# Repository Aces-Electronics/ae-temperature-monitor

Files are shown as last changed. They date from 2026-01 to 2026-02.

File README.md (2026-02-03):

# AE Temperature Monitor Firmware
Firmware for the Aces Electronics Temperature Monitor, utilizing ESP-NOW for low-latency communication with the Smart Shunt gateway.

## Features
- **Remote Monitoring**: Measures temperature using a high-accuracy sensor.
- **Battery Powered**: Optimized for low-power operation.
- **Wireless Relay**: Transmits data to the Smart Shunt via ESP-NOW.
- **Auto-Discovery**: Automatically detected and registered by the Smart Shunt and Cloud Dashboard.

## Communication Protocol (ESP-NOW)
The Sensor broadcasts a `struct_message_temp_sensor` payload which is received by the Smart Shunt. The Shunt then relays this data to the Cloud Dashboard for real-time alerts and historical logging.

## Build & Flash
The project uses PlatformIO.
```bash
pio run -t upload
pio run -t upload
```

## OTA Reliability
- **Loop Prevention**: Rejects updates if the version matches the currently installed firmware.
- **JIT Delivery**: Updates are pushed via the Shunt gateway immediately after an uplink.

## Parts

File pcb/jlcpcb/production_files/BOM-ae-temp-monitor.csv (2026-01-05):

Comment | Designator | Footprint | LCSC | Quantity
SW_Push | SW1,SW2 | ALPSALPINE-SKSCLBE010_C115361 | C115361 | 2
100nF | C1,C2,C3,C4,C5 | C_0402_1005Metric | C1525 | 5
1N5819WS | D1 | D_SOD-323 | C191023 | 1
10uF | C6,C7 | C_0603_1608Metric | C19702 | 2
100k | R2 | R_0402_1005Metric | C25741 | 1
5.1k | R1,R3,R4,R5,R6 | R_0402_1005Metric | C25905 | 5
ESP32-C3-MINI-1 | U1 | ESP32-C3-MINI-1 | C2838502 | 1
AP2112K-3.3 | U4 | SOT-23-5 | C51118 | 1
USB_C_Receptacle_USB2.0 | J1 | USB_C_Receptacle_GCT_USB4110 | C5187472 | 1
AP3415E | Q1 | SOT-23 | C5189719 | 1
Battery | BT2 | BatteryHolder_BH-AAA-B5AK001_C964882 | C964882 | 1
WS2812-2020 | D2 | LED_WS2812B-2020_PLCC4_2.0x2.0mm | C965555 | 1
TMP102xxDRL | U2 | SOT-563 | C99269 | 1

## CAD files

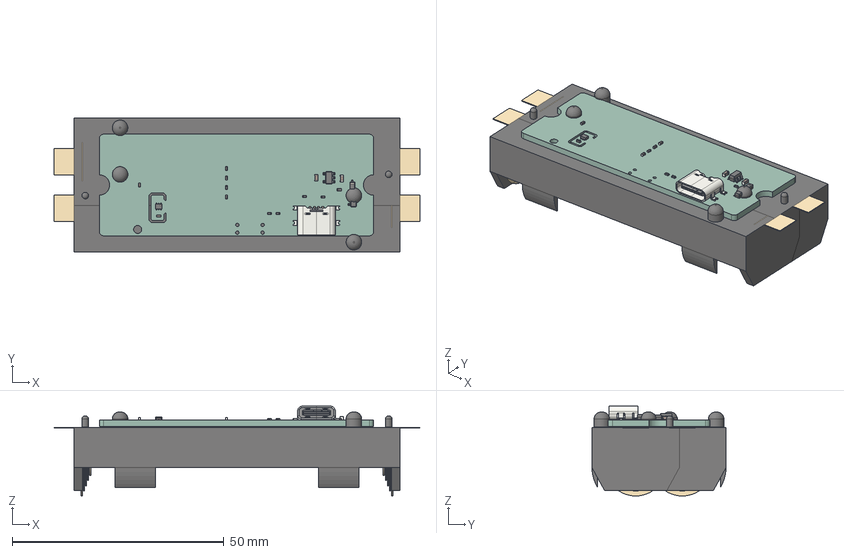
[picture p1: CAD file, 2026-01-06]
pcb/ae-temp-monitor.step
86.4 x 31.7 x 21.2 mm
C_0402_1005Metric x 5
USB_C_Receptacle_GCT_USB4135-GF-A_6P_TopMnt_Horizontal
R_0402_1005Metric x 6
SOT-563
SOT-23
D_SOD-323
C_0603_1608Metric x 2
SOT-23-5
BatteryHolder_Keystone_1042_1x18650 x 2
ae-temp-monitor_PCB

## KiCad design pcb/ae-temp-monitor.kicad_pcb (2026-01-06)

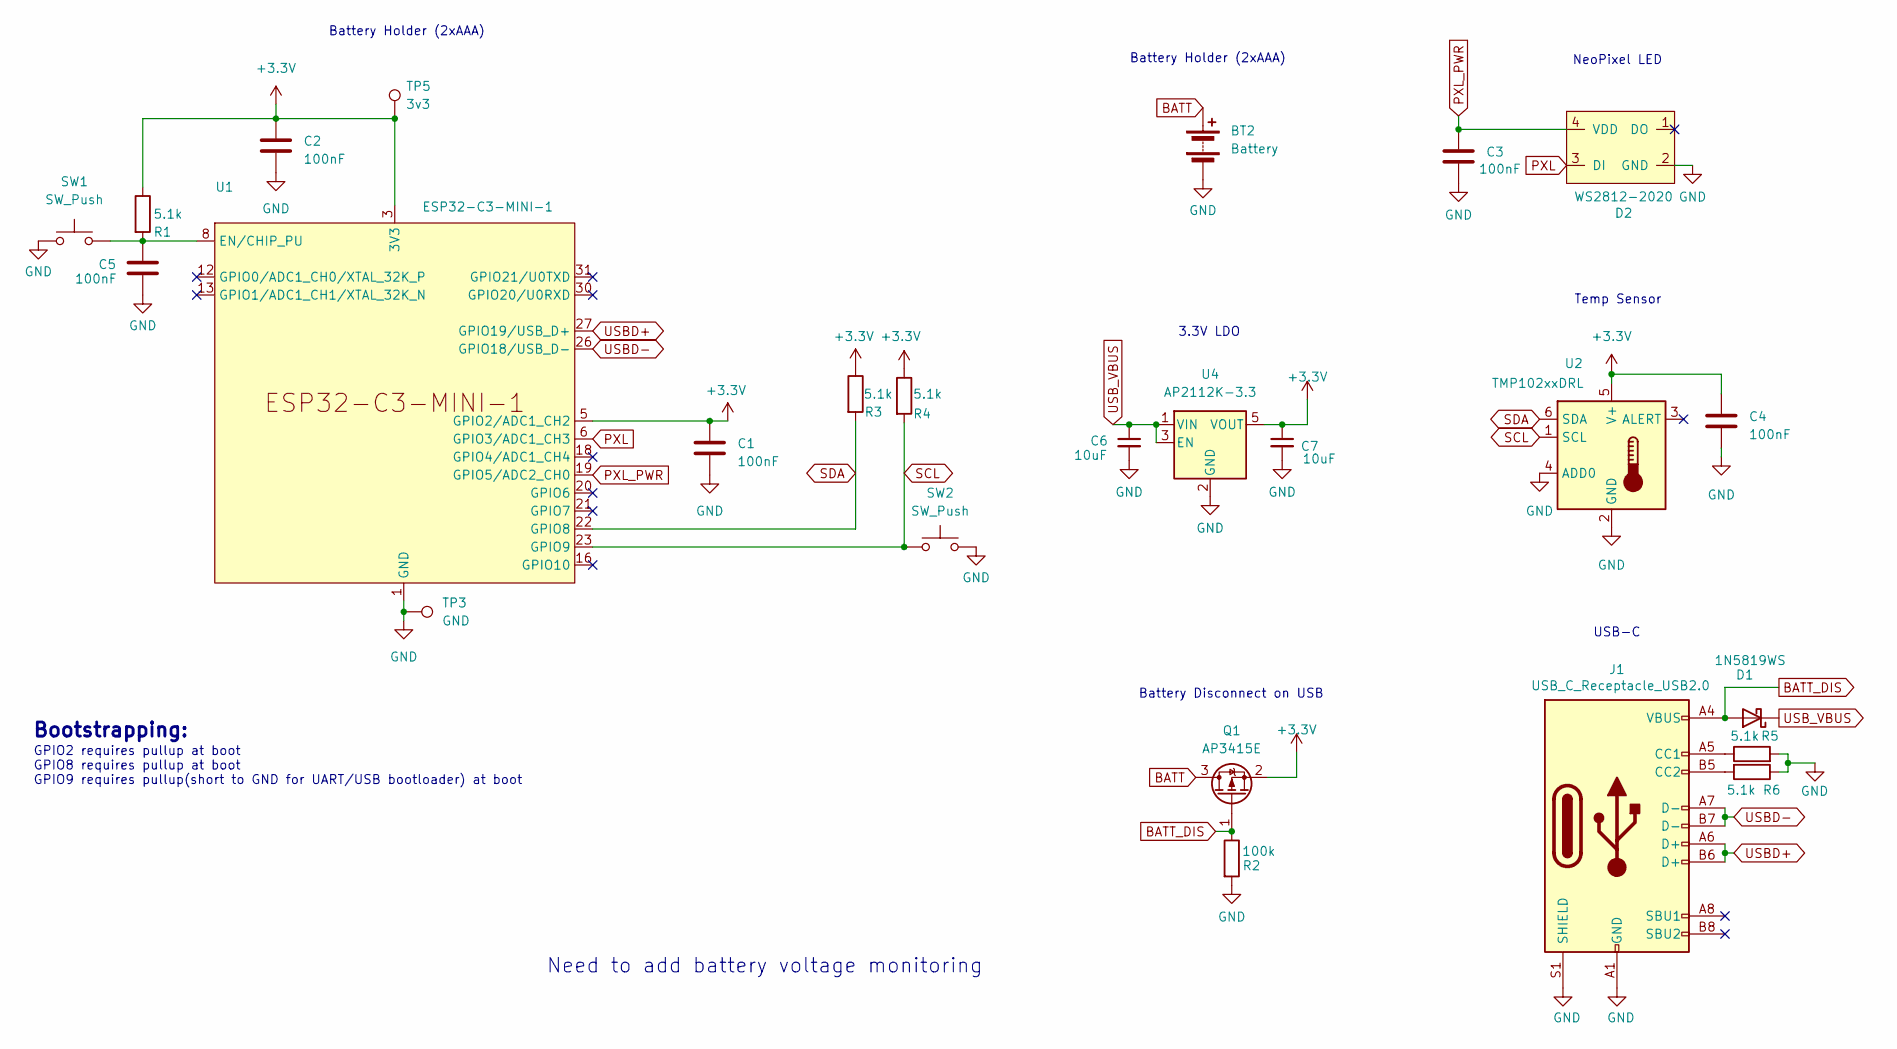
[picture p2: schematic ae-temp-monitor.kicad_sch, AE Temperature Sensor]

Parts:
BT2: Battery; BatteryHolder_BH-AAA-B5AK001_C964882; lcsc C964882
C1, C2, C3, C4, C5: 100nF; C_0402_1005Metric; lcsc C1525
C6, C7: 10uF; C_0603_1608Metric; lcsc C19702
D1: 1N5819WS; D_SOD-323; lcsc C191023
D2: WS2812-2020; LED_WS2812B-2020_PLCC4_2.0x2.0mm; lcsc C965555
J1: USB_C_Receptacle_USB2.0; USB_C_Receptacle_GCT_USB4110; lcsc C5187472
Q1: AP3415E; SOT-23; lcsc C2876004
R1, R3, R4, R5, R6: 5.1k; R_0402_1005Metric; lcsc C25905
R2: 100k; R_0402_1005Metric; lcsc C25741
SW1, SW2: SW_Push; ALPSALPINE-SKSCLBE010_C115361; lcsc C115361
TP3: GND; TestPoint_Pad_D1.0mm
TP5: 3v3; TestPoint_Pad_D1.0mm
U1: ESP32-C3-MINI-1; lcsc C5290152
U2: TMP102xxDRL; SOT-563; lcsc C99269
U4: AP2112K-3.3; SOT-23-5; lcsc C51118

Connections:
+3.3V: C1.1, C2.1, C4.1, C7.1, Q1.2 (S), R1.1, R3.1, R4.1, TP5.1, U1.3 (3V3), U1.5 (GPIO2/ADC1_CH2), U2.5 (V+), U4.5 (VOUT)
BATT: BT2.1 (+), Q1.3 (D)
BATT_DIS: D1.2 (A), J1.A4 (VBUS), J1.A9 (VBUS), J1.B4 (VBUS), J1.B9 (VBUS), Q1.1 (G), R2.1
GND: BT2.2 (-), C1.2, C2.2, C3.2, C4.2, C5.2, C6.2, C7.2, D2.2 (GND), J1.A1 (GND), J1.A12 (GND), J1.B1 (GND), J1.B12 (GND), J1.S1 (SHIELD), R2.2, R5.2, R6.1, SW1.2, SW2.2, TP3.1, U1.1 (GND), U1.2 (GND), U1.11 (GND), U1.14 (GND), U1.36 (GND), U1.37 (GND), U1.38 (GND), U1.39 (GND), U1.40 (GND), U1.41 (GND), U1.42 (GND), U1.43 (GND), U1.44 (GND), U1.45 (GND), U1.46 (GND), U1.47 (GND), U1.48 (GND), U1.49 (GND), U1.50 (GND), U1.51 (GND), U1.52 (GND), U1.53 (GND), U2.2 (GND), U2.4 (ADD0), U4.2 (GND)
unnamed: J1.A5 (CC1), R5.1
unnamed: J1.B5 (CC2), R6.2
unnamed: C5.1, R1.2, SW1.1, U1.8 (EN/CHIP_PU)
PXL: D2.3 (DI), U1.6 (GPIO3/ADC1_CH3)
PXL_PWR: C3.1, D2.4 (VDD), U1.19 (GPIO5/ADC2_CH0)
SCL: R4.2, SW2.1, U1.23 (GPIO9), U2.1 (SCL)
SDA: R3.2, U1.22 (GPIO8), U2.6 (SDA)
USBD+: J1.A6 (D+), J1.B6 (D+), U1.27 (GPIO19/USB_D+)
USBD-: J1.A7 (D-), J1.B7 (D-), U1.26 (GPIO18/USB_D-)
USB_VBUS: C6.1, D1.1 (K), U4.1 (VIN), U4.3 (EN)

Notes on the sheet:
Bootstrapping:
Battery Disconnect on USB
Temp Sensor
3.3V LDO
GPIO2 requires pullup at boot GPIO8 requires pullup at boot GPIO9 requires pullup(short to GND for UART/USB bootloader) at boot
NeoPixel LED
Need to add battery voltage monitoring
USB-C
Battery Holder (2xAAA)

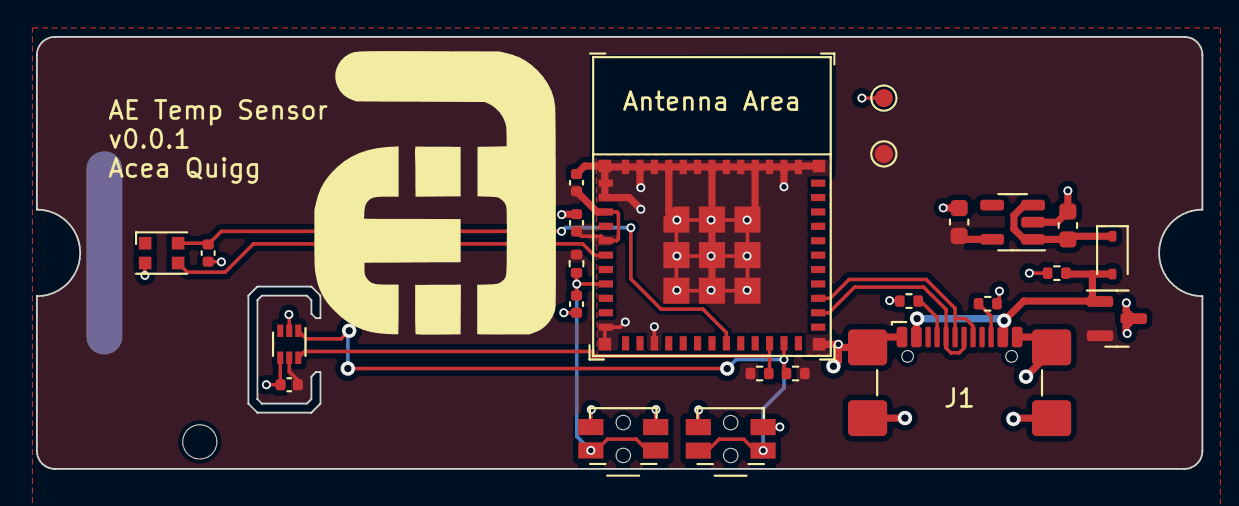
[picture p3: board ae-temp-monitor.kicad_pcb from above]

Board: 2 copper layers, 64.8 x 24.0 mm, 25 parts (1 on the bottom side), 14 nets.

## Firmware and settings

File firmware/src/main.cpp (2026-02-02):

#include <Arduino.h>
#include <Wire.h>
#include <Preferences.h>
#include "drivers/tmp102.h"
#include "drivers/neopixel.h"
#include "services/ble_service.h"
#include <services/espnow_service.h>
#include <nvs_flash.h>
#include <driver/gpio.h>
#include <WiFiClientSecure.h>

// Pins
#define I2C_SDA 8
#define I2C_SCL 9
#define NEOPIXEL_PWR 5
#define NEOPIXEL_PWR 5
#define NEOPIXEL_DATA 3
#define BOOT_PIN 9

#include <OTA-Hub.hpp>
#include <ota-github-cacerts.h>

// Globals
TMP102 tmp102;
StatusLed statusLed(NEOPIXEL_PWR, NEOPIXEL_DATA);
Preferences preferences;

// Constants
#define DEFAULT_SLEEP_MS 900000 // 15 minutes
#define AWAKE_TIME_MS 30000     // Stay awake for 30s to allow connections

unsigned long stateStartTime = 0;
bool isStayingAwake = false;

uint8_t g_pairedMac[6] = {0}; // Global storage for paired MAC
bool g_isTimerWakeup = false;

volatile bool g_indirectOtaPending = false;
struct_message_ota_trigger g_otaTrigger;

void onDataRecv(const uint8_t * mac, const uint8_t *incomingData, int len) {
    if (len == sizeof(struct_message_ota_trigger)) {
        struct_message_ota_trigger trigger;
        memcpy(&trigger, incomingData, sizeof(trigger));
        if (trigger.messageID == 110) {
            trigger.version[sizeof(trigger.version)-1] = '\0'; // Safety
            Serial.printf("[ESP-NOW] OTA Trigger: Ver='%s' (Current='%s'), Force=%d\n", 
                          trigger.version, OTA_VERSION, trigger.force);

            if (!trigger.force && strcmp(trigger.version, OTA_VERSION) == 0) {
                Serial.println("[ESP-NOW] OTA Ignored: Already on target version.");
                return;
            }

            Serial.println("[ESP-NOW] OTA Trigger Accepted!");
            memcpy((void*)&g_otaTrigger, &trigger, sizeof(g_otaTrigger));
            g_indirectOtaPending = true;
        }
    }
}

void setup() {
    Serial.begin(115200);
    // Wait a bit for serial if USB connected
    delay(1000); 
    Serial.println("AE Temp Sensor Starting...");
    
    gpio_hold_dis((gpio_num_t)NEOPIXEL_PWR);
    gpio_hold_dis((gpio_num_t)NEOPIXEL_DATA); // Release Data Pin Hold
    gpio_deep_sleep_hold_dis(); 
    gpio_deep_sleep_hold_dis(); // Ensure global hold is off if used
    
    // Init Boot Pin
    pinMode(BOOT_PIN, INPUT_PULLUP);

    // Check Wakeup Cause
    if (esp_sleep_get_wakeup_cause() == ESP_SLEEP_WAKEUP_TIMER) {
        g_isTimerWakeup = true;
        Serial.println("Wakeup: TIMER (Fast Sleep Mode)");
    } else {
        Serial.println("Wakeup: MANUAL/POWER (POR) -> Staying Awake 30s");
        isStayingAwake = true; // Ensure 30s awake window on boot/manual reset
    }

    // Init NVS
    preferences.begin("ae-temp", false);
    uint32_t sleepInterval = preferences.getUInt("sleep_ms", DEFAULT_SLEEP_MS);
    
    // Load Name Suffix (previously "name")
    String nameSuffix = preferences.getString("name", ""); 
    Serial.printf("DEBUG: Loaded Name Suffix from NVS: '%s'\n", nameSuffix.c_str());
    
    String deviceName = "AE Temp Sensor";
    if (nameSuffix.length() > 0) {
        deviceName += " - " + nameSuffix;
    }
    Serial.printf("DEBUG: Full Device Name for BLE: '%s'\n", deviceName.c_str());
    
    bleService.setSleepInterval(sleepInterval);
    bleService.setNameCallback([](const char* suffix) {
        // Save only the suffix
        preferences.putString("name", suffix);
        Serial.printf("Saved new name suffix to NVS: %s\n", suffix);
    });

    bool isPaired = preferences.getBool("paired", false);
    bleService.setPaired(isPaired);
    bleService.setPairedCallback([](bool paired) {
        preferences.putBool("paired", paired);
        Serial.printf("Saved Paired Status to NVS: %s\n", paired ? "True" : "False");
        statusLed.flash(0, 128, 0, 500); // Green confirmation (Dimmed)
        
        if (!paired) {
            Serial.println("Factory Reset/Unpair Triggered!");
            // Visual confirmation: Long Red Flash
            statusLed.flash(255, 0, 0, 1000); 
            
            // Wipe Everything
            preferences.clear(); // Explicitly clear the 'ae-temp' namespace keys
            nvs_flash_erase();   // Wipe the underlying partition
            nvs_flash_init();
            
            Serial.println("NVS Erased. Restarting...");
            delay(500);
            ESP.restart();
        }
    });
    
    // Handle JSON Pairing Data {"gauge_mac":"...", "key":"..."}
    bleService.setPairingDataCallback([](const char* json) {
        Serial.printf("Processing Pairing JSON/CMD: %s\n", json);
        
        if (String(json) == "PAIRING") {
            Serial.println("Received PAIRING command via BLE. Forcing broadcast mode for 5 mins.");
            espNowService.setForceBroadcast(true);
            // We use a global or local static to track time
            return;
        }

        // Minimal JSON parsing to avoid heavy library usage if possible, or use ArduinoJson if available (user has it in other projects)
        // Let's assume ArduinoJson is available or use String search
        String j = String(json);
        
        // Extract MAC
        int macIdx = j.indexOf("gauge_mac");
        String gaugeMacStr = "";
        if (macIdx > 0) {
            int start = j.indexOf(":", macIdx) + 1;
            // Skip quotes
            while (j[start] == ' ' || j[start] == '"') start++;
            int end = j.indexOf('"', start);
            gaugeMacStr = j.substring(start, end);
        }
        
        // Extract Key
        int keyIdx = j.indexOf("key");
        String keyStr = "";
        if (keyIdx > 0) {
            int start = j.indexOf(":", keyIdx) + 1;
            while (j[start] == ' ' || j[start] == '"') start++;
            int end = j.indexOf('"', start);
            keyStr = j.substring(start, end);
        }
        
        Serial.printf("Extracted MAC: %s, Key: %s\n", gaugeMacStr.c_str(), keyStr.c_str());
        
        if (gaugeMacStr.length() > 0 && keyStr.length() == 32) {
             preferences.putString("p_mac", gaugeMacStr);
             preferences.putString("p_key", keyStr);
             
             // Update Global MAC for main loop
             sscanf(gaugeMacStr.c_str(), "%hhx:%hhx:%hhx:%hhx:%hhx:%hhx", 
               &g_pairedMac[0], &g_pairedMac[1], &g_pairedMac[2], 
               &g_pairedMac[3], &g_pairedMac[4], &g_pairedMac[5]);
             
             // Update runtime peer immediately
             espNowService.addSecurePeer(gaugeMacStr.c_str(), keyStr.c_str());
             
             bleService.updatePaired(true); // Notify App success
        } else {
            Serial.println("Invalid Pairing Data");
        }
    });

    bleService.setWifiCallback([](const char* ssid, const char* pass) {
        Serial.printf("Received WiFi Creds via BLE: SSID='%s'\n", ssid);
        // Store in global trigger struct for upcoming OTA
        memset(&g_otaTrigger, 0, sizeof(g_otaTrigger)); // Clear first to avoid garbage
        g_otaTrigger.messageID = 110;
        strncpy(g_otaTrigger.ssid, ssid, sizeof(g_otaTrigger.ssid) - 1);
        strncpy(g_otaTrigger.pass, pass, sizeof(g_otaTrigger.pass) - 1);
        // Force flag is set in Force Callback
    });

    bleService.setForceOtaCallback([]() {
        Serial.println("FORCE OTA Triggered via Direct BLE!");
        // We assume WiFi creds were just sent.
        // If not, we might fail to connect.
        // Check if SSID is present?
        if (strlen(g_otaTrigger.ssid) == 0) {
             Serial.println("Aborting Force OTA: No WiFi SSID set.");
             return;
        }

        g_otaTrigger.messageID = 110;
        g_otaTrigger.force = true;
        // URL left empty -> triggers OTA::isUpdateAvailable() logic in loop()
        
        g_indirectOtaPending = true;
    });

    // Init Drivers
    Wire.begin(I2C_SDA, I2C_SCL); // Init Wire before TMP102
    if (!tmp102.begin(I2C_SDA, I2C_SCL)) {
        Serial.println("TMP102 Init Failed!");
    } else {
        tmp102.wakeup(); // Ensure continuous conversion mode
        delay(35);       // Allow time for first conversion (26ms typical)
    }
    
    statusLed.begin();
    statusLed.begin();
    // statusLed.flash(0, 128, 0, 200); // REMOVED: Silent Boot

    // Load Paired MAC if exists - MOVED down after begin()

    // Init Services
    espNowService.begin();
    espNowService.registerRecvCallback(onDataRecv);
    bleService.begin(deviceName.c_str());
    // Ensure the characteristic holds only the suffix for editing
    bleService.updateName(nameSuffix.c_str());
    
    // Load Paired MAC if exists (MUST be after espNowService.begin)
    String savedMac = preferences.getString("p_mac", "");
    if (savedMac.length() > 0) {
        sscanf(savedMac.c_str(), "%hhx:%hhx:%hhx:%hhx:%hhx:%hhx", 
               &g_pairedMac[0], &g_pairedMac[1], &g_pairedMac[2], 
               &g_pairedMac[3], &g_pairedMac[4], &g_pairedMac[5]);
        
        String savedKey = preferences.getString("p_key", "");
        if (savedKey.length() == 32) {
             espNowService.addSecurePeer(savedMac.c_str(), savedKey.c_str());
        }
    }
    
    // Ensure Paired Char has correct MAC (Redundant if set in begin, but safe)
    // bleService update handled in begin()

    // Read Sensors
    float temp = tmp102.readTemperature();
    Serial.printf("Temperature: %.2f C\n", temp);
    
    // Reset Send Status before sending
    espNowService.resetSendStatus();

    // Broadcast ESPNow
    TempSensorData data;
    data.id = 22;
    data.temperature = temp;
    data.batteryVoltage = 3.3; // Placeholder
    data.batteryLevel = 100;   // Placeholder
    data.updateInterval = bleService.getSleepInterval();
    data.hardwareVersion = HW_VERSION;
    strncpy(data.firmwareVersion, String(OTA_VERSION).c_str(), sizeof(data.firmwareVersion) - 1);
    memset(data.name, 0, sizeof(data.name));
    strncpy(data.name, deviceName.c_str(), sizeof(data.name) - 1);

    // Send Data (Unicast if Paired, Broadcast if Not)
    bool isPairedLocal = bleService.isPaired(); 
    // Fallback: Check global MAC if flag is inconsistent
    if (!isPairedLocal && (g_pairedMac[0] != 0 || g_pairedMac[1] != 0)) {
         isPairedLocal = true;
    }

    if (isPairedLocal) {
         espNowService.sendToPeer(data, g_pairedMac);
    } else {
         espNowService.broadcast(data);
         statusLed.flash(64, 64, 64, 50); // White Flash (Broadcast/Discovery)
    }

    // WAIT FOR SEND FINISH (Essential for Fast Sleep)
    unsigned long sendStart = millis();
    while (!espNowService.sendFinished && (millis() - sendStart < 100)) {
        delay(1);
    }
    
    if (espNowService.sendFinished) {
         if (espNowService.sendSuccess) {
             delay(5); // success, small buffer
         } else {
             Serial.println("ESP-NOW Send Failed!");
             statusLed.flash(255, 128, 0, 50); // Orange Flash (Send Fail)
         }
    } else {
         Serial.println("ESP-NOW Send Timeout!");
    }

    // Update BLE
    bleService.updateTemperature(temp);
    bleService.updateBatteryLevel(100);

    stateStartTime = millis();
}

// Include ESP WiFi for channel switching
#include <esp_wifi.h>

void loop() {
    // Check for sleep interval change from BLE
    static uint32_t lastSleepInterval = bleService.getSleepInterval();
    if (bleService.getSleepInterval() != lastSleepInterval) {
        lastSleepInterval = bleService.getSleepInterval();
        preferences.putUInt("sleep_ms", lastSleepInterval);
        Serial.println("Saved new sleep interval to NVS");
        statusLed.flash(0, 0, 128, 200); // Blue flash on save (Dimmed)
    }

    // BLE Maintenance
    if (bleService.isConnected()) {
        isStayingAwake = true;
        
        static unsigned long lastUpdate = 0;
        if (millis() - lastUpdate > 5000) {
            float temp = tmp102.readTemperature();
            bleService.updateTemperature(temp);
            
            // Broadcast ESP-NOW Data so Gauge can see it during pairing
            // CYCLE CHANNELS to ensure Gauge finds us regardless of its WiFi channel
            TempSensorData data;
            data.id = 22; 
            data.temperature = temp;
            data.batteryVoltage = 3.3; 
            data.batteryLevel = 100;
            data.updateInterval = 5000; // 5 seconds when connected/awake
            data.hardwareVersion = HW_VERSION;
            strncpy(data.firmwareVersion, String(OTA_VERSION).c_str(), sizeof(data.firmwareVersion) - 1);

            String suffix = preferences.getString("name", "");
            String nameForEspNow = "AE Temp Sensor";
            if (suffix.length() > 0) nameForEspNow += " - " + suffix;
            
            // Start with Generic Broadcast Address
            memset(data.name, 0, sizeof(data.name));
            strncpy(data.name, nameForEspNow.c_str(), sizeof(data.name) - 1);

            // If Paired, send unicast to Gauge Address (Secure Peer)
            // If Not Paired, broadcast to FF:FF... on all channels
            
            bool isPaired = bleService.isPaired();
            // Robustness: If NVS or Flag is wrong, check if we have the peer loaded (and Global Mac set)
            if (!isPaired && (g_pairedMac[0] != 0 || g_pairedMac[1] != 0)) {
                 if (esp_now_is_peer_exist(g_pairedMac)) {
                     Serial.println("DEBUG: isPaired flag was false, but Secure Peer exists. Forcing Paired Mode.");
                     isPaired = true;
                     bleService.setPaired(true); // Sync flag
                 }
            }
            
            if (isPaired || espNowService.isForceBroadcast()) {
                 // UNICAST ENCRYPTED to GAUGE (or Broadcast if forced)
                 if (espNowService.isForceBroadcast()) {
                      // Forced Broadcast during Pairing
                      Serial.println("PAIRING MODE: Sending Broadcast Burst...");
                      statusLed.flash(0, 0, 128, 50); 
                      for (int ch = 1; ch <= 13; ch++) {
                         esp_wifi_set_channel(ch, WIFI_SECOND_CHAN_NONE);
                         delay(10); 
                         espNowService.broadcast(data);
                      }
                      esp_wifi_set_channel(1, WIFI_SECOND_CHAN_NONE);
                      
                      static unsigned long pairingStartTime = millis();
                      if (millis() - pairingStartTime > 300000) {
                          Serial.println("Pairing Mode Timeout (5 mins).");
                          espNowService.setForceBroadcast(false);
                      }
                 }
                 
                 if (isPaired) {
                      espNowService.sendToPeer(data, g_pairedMac);
                      statusLed.flash(0, 128, 0, 50); // Green Flash on Unicast (Dimmed)
                 }
            } else {
                 // BROADCAST Cycling (Hunt for Gauge)
                 // Only needed during initial discovery when NOT paired
                 statusLed.flash(0, 0, 128, 50); // Blue Flash on Broadcast Burst (Dimmed)
                 for (int ch = 1; ch <= 13; ch++) {
                    esp_wifi_set_channel(ch, WIFI_SECOND_CHAN_NONE);
                    delay(10); 
                    espNowService.broadcast(data);
                 }
                 esp_wifi_set_channel(1, WIFI_SECOND_CHAN_NONE);
            }
            
            lastUpdate = millis();
        }
    } else {
        isStayingAwake = false;
    }

    // Deep Sleep Logic: Only if Paired
    if (bleService.isPaired()) {
        uint32_t awakeWindow = g_isTimerWakeup ? 200 : AWAKE_TIME_MS; 
        
        if (!isStayingAwake && (millis() - stateStartTime > awakeWindow)) {
            uint32_t sleepMs = bleService.getSleepInterval();
            
            // Only sleep if interval is > 0. If 0, we stay awake (Always On).
            if (sleepMs > 0) {
                Serial.printf("Going to sleep for %u ms...\n", sleepMs);
                statusLed.off();
                // Shutdown Sensor
                if (!tmp102.shutdown()) {
                    Serial.println("TMP102 Shutdown Failed!");
                    statusLed.flash(255, 0, 0, 50); // Red Flash
                }
                
                // --- PHANTOM POWER FIX ---
                // Drive Data Pin LOW and Hold it to prevent leakage into LED
                pinMode(NEOPIXEL_DATA, OUTPUT);
                digitalWrite(NEOPIXEL_DATA, LOW);
                gpio_hold_en((gpio_num_t)NEOPIXEL_DATA);

                // Hold NeoPixel Power LOW
                gpio_hold_en((gpio_num_t)NEOPIXEL_PWR);
                gpio_deep_sleep_hold_en(); // Enable Global Hold Logic
                
                // --- I2C BUS RECOVERY & LEAKAGE FIX ---
                Wire.end(); // Stop I2C Driver
                
                // Manual Bus Clear: Toggle SCL 9 times to unstick slave
                pinMode(I2C_SDA, INPUT_PULLUP);
                pinMode(I2C_SCL, OUTPUT);
                for (int i = 0; i < 9; i++) {
                    digitalWrite(I2C_SCL, HIGH);
                    delayMicroseconds(5);
                    digitalWrite(I2C_SCL, LOW);
                    delayMicroseconds(5);
                }
                // Stop Condition (SDA Low -> High while SCL High)
                pinMode(I2C_SDA, OUTPUT);
                digitalWrite(I2C_SDA, LOW);
                delayMicroseconds(5);
                digitalWrite(I2C_SCL, HIGH);
                delayMicroseconds(5);
                digitalWrite(I2C_SDA, HIGH);
                delayMicroseconds(5);

                // Final State: Input Pullup (High-Z + Pullup)
                pinMode(I2C_SDA, INPUT_PULLUP);
                pinMode(I2C_SCL, INPUT_PULLUP); 

                // --- GPIO WAKEUP FIX ---
                // Explicitly valid input config for Deep Sleep (AFTER Reset)
                gpio_config_t io_conf = {};
                io_conf.intr_type = GPIO_INTR_DISABLE;
                io_conf.mode = GPIO_MODE_INPUT;
                io_conf.pin_bit_mask = (1ULL << BOOT_PIN);
                io_conf.pull_down_en = GPIO_PULLDOWN_DISABLE;
                io_conf.pull_up_en = GPIO_PULLUP_ENABLE;
                gpio_config(&io_conf);

                // --- DEEP SLEEP START ---
                // Note: GPIO9 (Boot) is NOT an RTC pin on C3, so we cannot wake from it in Deep Sleep.
                // We only wake on Timer.
                
                uint64_t sleepUs = (uint64_t)sleepMs * 1000ULL;
                esp_sleep_enable_timer_wakeup(sleepUs);
                esp_deep_sleep_start();
            } else {
                 // Optional: Periodic debug to confirm we are awake
                 static unsigned long lastAwakeLog = 0;
                 if (millis() - lastAwakeLog > 10000) {
                     Serial.println("Always On Mode: Staying Awake...");
                     lastAwakeLog = millis();
                 }
            }
        }
    } else {
        // Not Paired: Stay Awake, Blue heartbeat to indicate "Ready to Pair"
        static unsigned long lastFlash = 0;
        if (millis() - lastFlash > 2000) {
             statusLed.flash(0, 0, 25, 100); // Faint Blue (Dimmed from 50)
             lastFlash = millis();
        }
    }

    // OTA Execution Logic
    if (g_indirectOtaPending) {
        g_indirectOtaPending = false;
        Serial.println("[OTA] Starting Update Process...");
        
        statusLed.flash(0, 0, 255, 500); // Blue Long Flash
        
        WiFi.disconnect(true);
        WiFi.mode(WIFI_STA);
        WiFi.begin(g_otaTrigger.ssid, g_otaTrigger.pass);
        
        int tries = 0;
        while (WiFi.status() != WL_CONNECTED && tries < 30) {
            delay(500);
            tries++;
            Serial.print(".");
        }
        
        if (WiFi.status() == WL_CONNECTED) {
            Serial.println("\n[OTA] WiFi Connected. Syncing Time...");
            configTime(0, 0, "pool.ntp.org", "time.nist.gov");
            delay(2000); 
            
            WiFiClientSecure client;
            client.setCACert(OTAGH_CA_CERT);
            OTA::init(client);

            OTA::UpdateObject obj;
            String url = String(g_otaTrigger.url);

            if (g_otaTrigger.force && url.length() == 0) {
                 Serial.println("[OTA] Force Update with Empty URL. Checking Defaults...");
                 obj = OTA::isUpdateAvailable();
                 if (obj.condition != OTA::NO_UPDATE) {
                     Serial.println("[OTA] Default Update Found. Forcing Install.");
                     obj.condition = OTA::NEW_DIFFERENT;
                 } else {
                     Serial.println("[OTA] No Default Update Found to Force.");
                 }
            } else {
                obj.condition = OTA::NEW_DIFFERENT;
                obj.tag_name = String(g_otaTrigger.version);
                
                if (url.startsWith("http")) {
                    int protoEnd = url.indexOf("://");
                    int pathStart = url.indexOf("/", protoEnd + 3);
                    if (pathStart > 0) {
                        obj.redirect_server = url.substring(protoEnd + 3, pathStart);
                        obj.firmware_asset_endpoint = url.substring(pathStart);
                    } else {
                        obj.firmware_asset_endpoint = url;
                    }
                } else {
                    obj.firmware_asset_endpoint = url;
                }
            }

            if (OTA::performUpdate(&obj, true, true, nullptr) == OTA::SUCCESS) {
                Serial.println("[OTA] Success! Restarting...");
                delay(1000);
                ESP.restart();
            }
        }
        Serial.println("\n[OTA] Failed or Canceled.");
        ESP.restart();
    }
    
    delay(10);
}

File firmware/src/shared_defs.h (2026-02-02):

#ifndef SHARED_DEFS_H
#define SHARED_DEFS_H

#include <stdint.h>

// Pin definitions
#define LOAD_SWITCH_PIN 5
#define INA_ALERT_PIN 7
#define LED_PIN 4

// NVS keys
#define NVS_CAL_NAMESPACE "ina_cal"
#define NVS_KEY_ACTIVE_SHUNT "active_shunt"
#define NVS_PROTECTION_NAMESPACE "protection"
#define NVS_KEY_LOW_VOLTAGE_CUTOFF "lv_cutoff"
#define NVS_KEY_HYSTERESIS "hysteresis"
#define NVS_KEY_OVERCURRENT "oc_thresh"
#define NVS_KEY_LOW_VOLTAGE_DELAY "lv_delay"
#define NVS_KEY_DEVICE_NAME_SUFFIX "name_suffix"
#define NVS_KEY_COMPENSATION_RESISTANCE "comp_res"
#define NVS_KEY_EFUSE_LIMIT "efuse_limit"

#define I2C_ADDRESS 0x40
const int scanTime = 5;

extern uint8_t broadcastAddress[6];

typedef struct {
  uint16_t vendorID;
  uint8_t beaconType;
  uint8_t unknownData1[3];
  uint8_t victronRecordType;
  uint16_t nonceDataCounter;
  uint8_t encryptKeyMatch;
  uint8_t victronEncryptedData[21];
  uint8_t nullPad;
} __attribute__((packed)) victronManufacturerData;

typedef struct {
   uint8_t deviceState;
   uint8_t outputState;
   uint8_t errorCode;
   uint16_t alarmReason;
   uint16_t warningReason;
   uint16_t inputVoltage;
   uint16_t outputVoltage;
   uint32_t offReason;
   uint8_t  unused[32];
} __attribute__((packed)) victronPanelData;

typedef struct struct_message_voltage0 {
  int messageID;
  bool dataChanged;
  float frontMainBatt1V;
  float frontAuxBatt1V;
  float rearMainBatt1V;
  float rearAuxBatt1V;
  float frontMainBatt1I;
  float frontAuxBatt1I;
  float rearMainBatt1I;
  float rearAuxBatt1I; 
} struct_message_voltage0;

// Core Telemetry sent over ESP-NOW Mesh (must be < 250 bytes)
typedef struct struct_message_ae_smart_shunt_mesh {
  int messageID;
  bool dataChanged;
  float batteryVoltage;
  float batteryCurrent;
  float batteryCurrentAvg; 
  float batteryPower;
  float batterySOC;
  float batteryCapacity;
  int batteryState;
  char runFlatTime[32]; 
  float starterBatteryVoltage;
  bool isCalibrated;
  float lastHourWh;
  float lastDayWh;
  float lastWeekWh;
  char name[32];   
  
  // TPMS Data (Relayed to Gauge)
  float tpmsPressurePsi[4];
  int tpmsTemperature[4];
  float tpmsVoltage[4];
  uint32_t tpmsLastUpdate[4];

  // Temp Sensor Data (Core fields relayed to Gauge)
  float tempSensorTemperature;
  uint8_t tempSensorBatteryLevel;
  uint32_t tempSensorUpdateInterval; 
  uint32_t tempSensorLastUpdate;
  char tempSensorName[32]; 

  // Hardware Version
  uint8_t hardwareVersion;
} __attribute__((packed)) struct_message_ae_smart_shunt_mesh;

// Full Telemetry used by Shunt for MQTT/Cloud (Internal use)
typedef struct struct_message_ae_smart_shunt_1 {
  struct_message_ae_smart_shunt_mesh mesh;
  
  // Extended Temp metadata (Relayed to Cloud only)
  uint8_t tempSensorHardwareVersion;
  char tempSensorFirmwareVersion[12];
  uint8_t tempSensorMac[6]; 

  // Gauge Data (Relayed to Cloud only)
  char gaugeName[32];
  uint8_t gaugeHardwareVersion;
  char gaugeFirmwareVersion[12];
  uint8_t gaugeMac[6]; 
  uint32_t gaugeLastUpdate;
} __attribute__((packed)) struct_message_ae_smart_shunt_1;

typedef struct struct_message_tpms_config {
  int messageID; // unique ID (e.g., 99)
  uint8_t macs[4][6];      // MAC Addresses
  float baselines[4];      // Baseline Pressures
  bool configured[4];      // Is sensor active?
} __attribute__((packed)) struct_message_tpms_config;

typedef struct struct_message_temp_sensor {
  uint8_t id;
  float temperature;
  float batteryVoltage;
  uint8_t batteryLevel;
  uint32_t updateInterval;
  char name[32];
  uint8_t hardwareVersion;
  char firmwareVersion[12];
} __attribute__((packed)) struct_message_temp_sensor;

typedef struct struct_message_add_peer {
  int messageID; // 200
  uint8_t mac[6];
  uint8_t key[16];
  uint8_t channel;
  bool encrypt;
} __attribute__((packed)) struct_message_add_peer;

// UI Helper Struct (Gauge only, but safe to include)
typedef struct {
    float inputVoltage;
    float outputVoltage;
    uint16_t alarmReason;
    uint8_t deviceState;
    uint8_t errorCode;
    uint16_t warningReason;
    uint32_t offReason;
    char deviceName[32];
} lv_ble_ui_data_t;

// Indirect OTA Trigger (from Gateway to Child)
typedef struct struct_message_ota_trigger {
  int messageID; // 110
  char ssid[33];
  char pass[65];
  char url[96];
  char version[12];
  char md5[33];
  bool force; // New Flag
} __attribute__((packed)) struct_message_ota_trigger;

// Backward Compatibility
typedef struct_message_temp_sensor struct_message_ae_temp_sensor;

#endif // SHARED_DEFS_H
